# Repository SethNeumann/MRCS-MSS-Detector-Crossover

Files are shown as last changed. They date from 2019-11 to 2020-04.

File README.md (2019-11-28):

# Modular Signaling System Crossover board cpOD-M
## License: CERN Open Hardware Licence v1.2

This Barry Draper design conforms to the 
[Modular Signaling System](http://modularsignalsystem.info/index.html)
(MSS) standard, first described by Greg Fuhriman in RMJ in the
1990s, as well as the proposed MSS 2.0 standard.  MSS is widely
used in the Free-mo world, but its also a great solution for a
layout needing basic ABS signaling.  A Crossover board is for a
non-signaled module (detection only).  The MSS Detector Crossover
Board includes a power supply that is fed by the Free-mo Aux Bus
(12 to 14 Volt AC or DCC) and has connectors to communicate with
two adjacent modules and a socket for current detector such as a
[cpOD-M](http://www.modelrailroadcontrolsystems.com/cpod-control-point-occupancy-detector/)
or Dr. Chubb's
[DCCOD](https://www.jlcenterprises.net/products/dcc-optimized-detector).
The MSS Crossover, a cpOD-M, and two straight-through network cables
are all you need to add signal detection to a single track Free-mo
module. (As expected, two of each would be needed for a double track
module.)

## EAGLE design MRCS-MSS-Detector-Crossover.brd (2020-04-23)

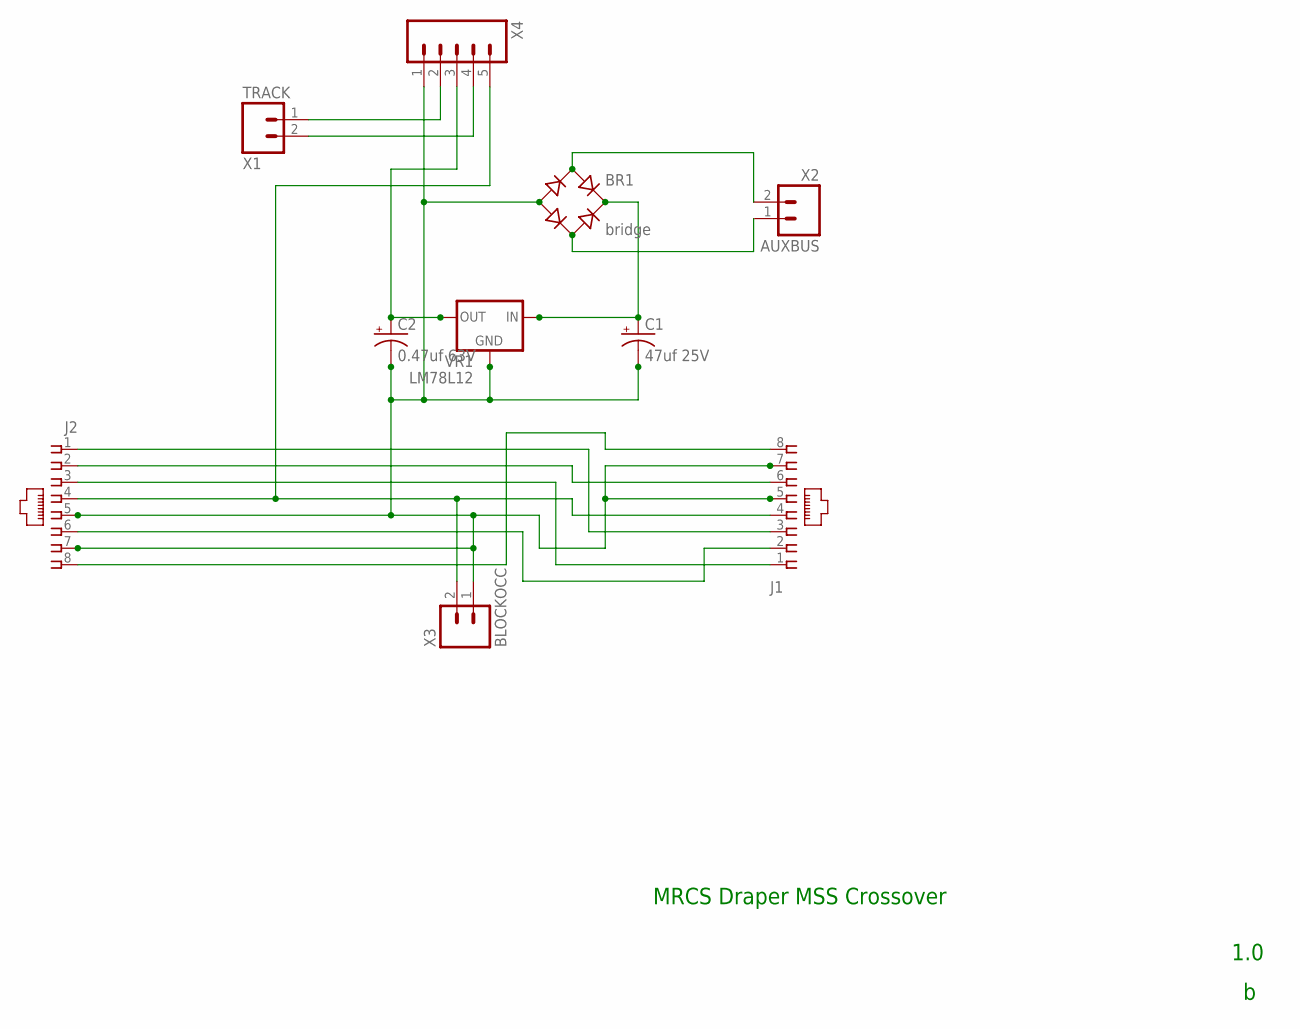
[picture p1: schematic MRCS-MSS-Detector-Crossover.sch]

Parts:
BR1: bridge; RB1A
C1: 47uf 25V; E2.5-6
C2: 0.47uf 63V; E2.5-6
J1, J2: CONNECTOR-RJ45-FRONT; RJ45-NO-SHIELD
VR1: LM78L12; TO-92
X1: TRACK; SCREWTERMINAL-5MM-2
X2: AUXBUS; SCREWTERMINAL-5MM-2
X3: BLOCKOCC; SCREWTERMINAL-5MM-2
X4: CONNECTOR-M051.56; KK-156-5

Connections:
AC1: BR1.AC1, X2.2 (B)
AC2: BR1.AC2, X2.1 (A)
GND: BR1.-, C1.-, C2.-, J1.5, J1.7, J2.5, J2.7, VR1.1 (GND), X3.1 (A), X4.1
unnamed: J1.3, J2.1
unnamed: J1.6, J2.2
unnamed: J1.1, J2.3
unnamed: J1.4, J2.4, X3.2 (B), X4.5
unnamed: J1.2, J2.6
unnamed: J1.8, J2.8
TRACK1: X1.1 (A), X4.2
TRACK2: X1.2 (B), X4.4
V12: C2.+, VR1.3 (OUT), X4.3
VIN: BR1.+, C1.+, VR1.2 (IN)

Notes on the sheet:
MRCS Draper MSS Crossover
1.0

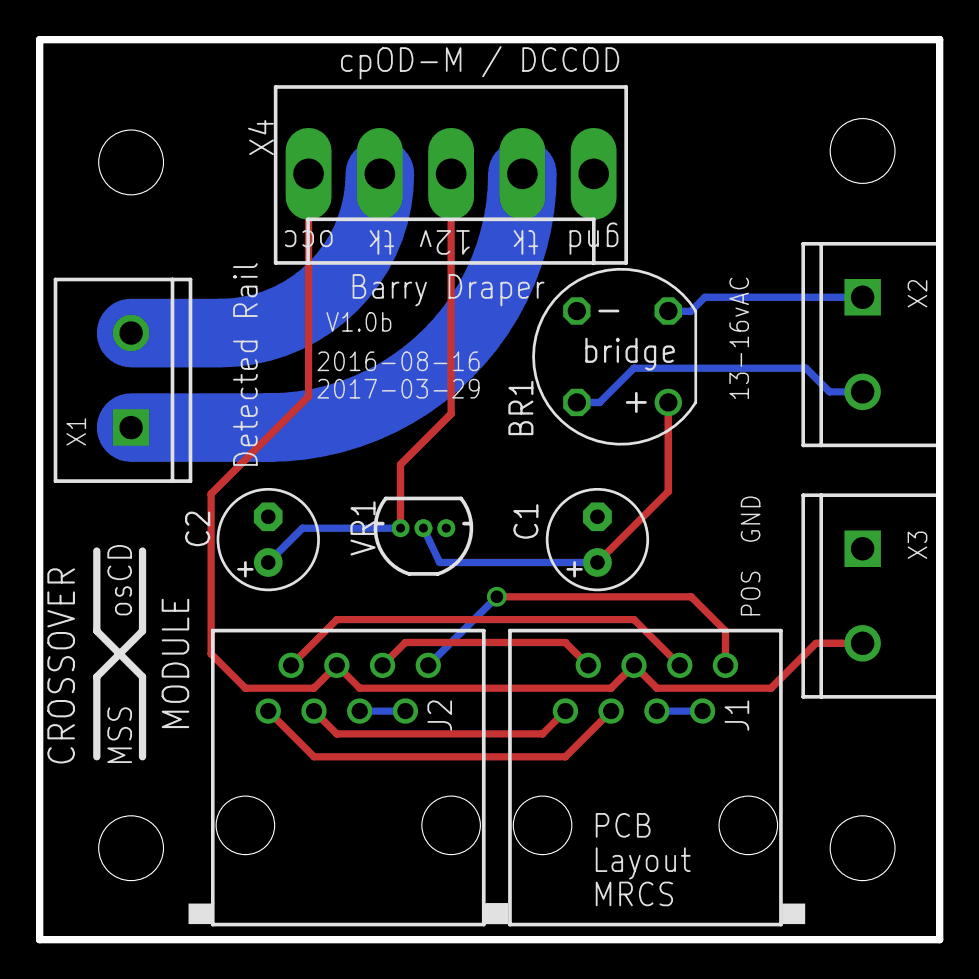
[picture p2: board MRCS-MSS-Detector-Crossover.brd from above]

Board: 2 copper layers, 50.0 x 50.0 mm, 10 parts (0 on the bottom side), 13 nets.

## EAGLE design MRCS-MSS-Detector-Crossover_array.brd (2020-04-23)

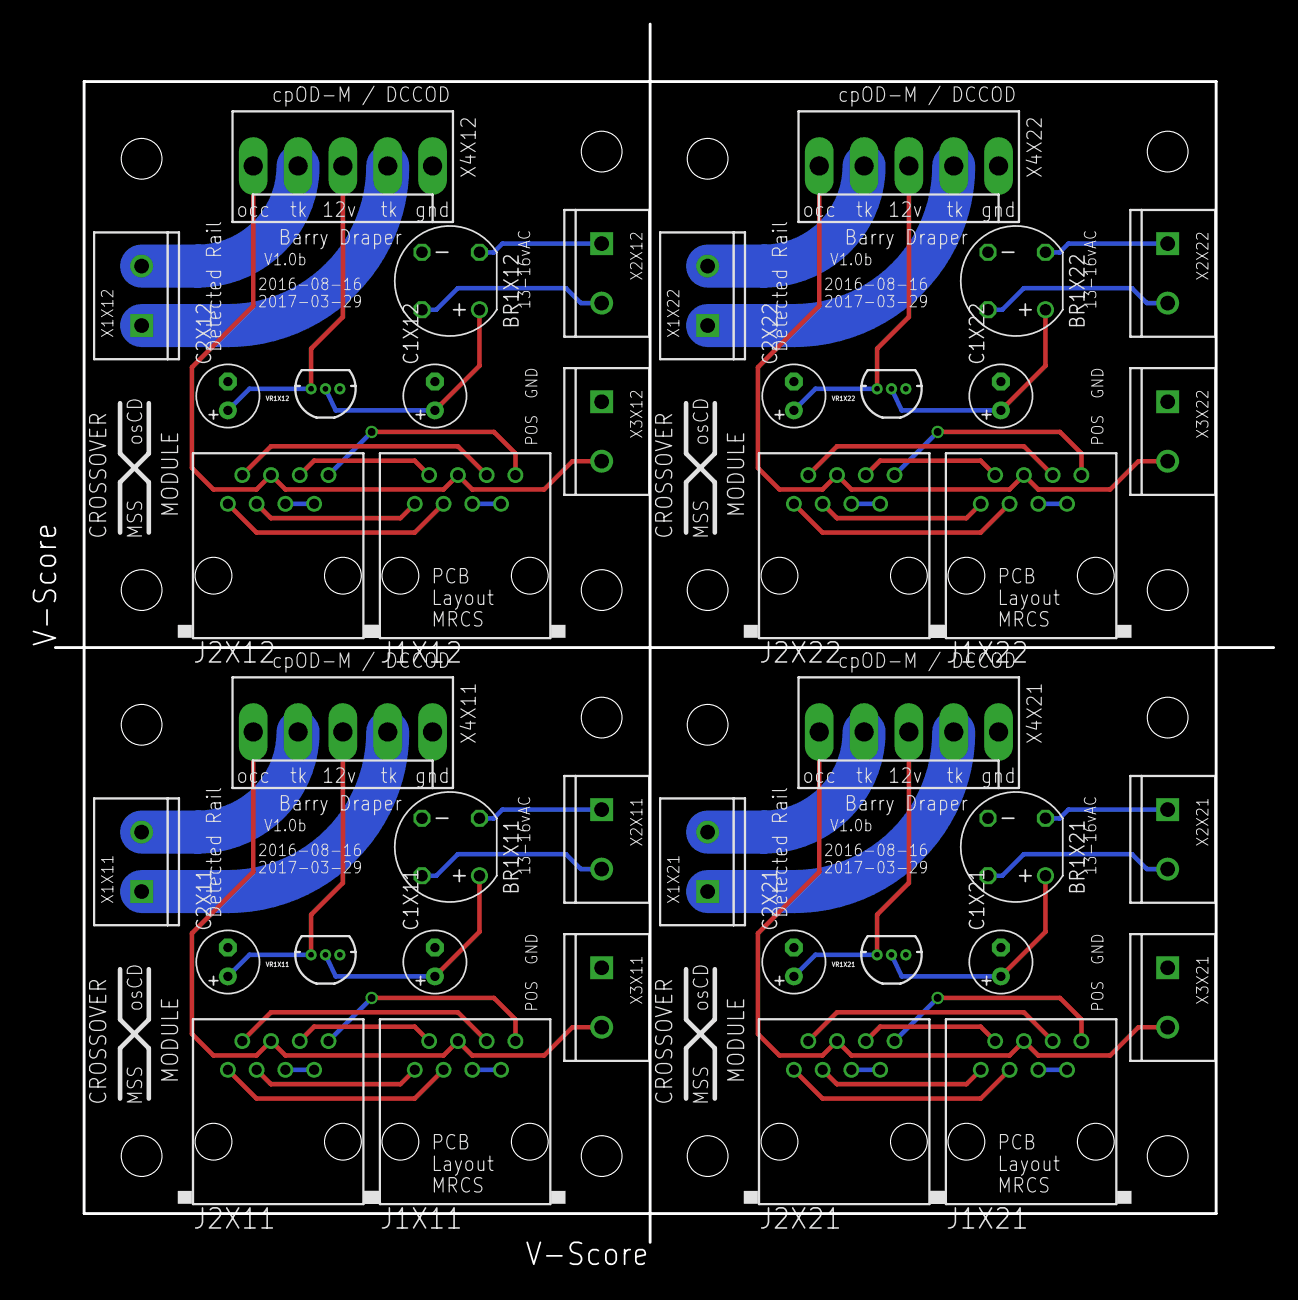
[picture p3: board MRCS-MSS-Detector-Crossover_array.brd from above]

Board: 2 copper layers, 107.6 x 107.6 mm, 40 parts (0 on the bottom side), 52 nets.

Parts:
BR1X11, BR1X12, BR1X21, BR1X22: RB1A
C1X11, C1X12, C1X21, C1X22, C2X11, C2X12, C2X21, C2X22: E2.5-6
J1X11, J1X12, J1X21, J1X22, J2X11, J2X12, J2X21, J2X22: RJ45-NO-SHIELD
VR1X11, VR1X12, VR1X21, VR1X22: TO-92
X1X11, X1X12, X1X21, X1X22, X2X11, X2X12, X2X21, X2X22, X3X11, X3X12, X3X21, X3X22: SCREWTERMINAL-5MM-2
X4X11, X4X12, X4X21, X4X22: KK-156-5

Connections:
AC1X11: BR1X11.AC1, X2X11.2
AC1X12: BR1X12.AC1, X2X12.2
AC1X21: BR1X21.AC1, X2X21.2
AC1X22: BR1X22.AC1, X2X22.2
AC2X11: BR1X11.AC2, X2X11.1
AC2X12: BR1X12.AC2, X2X12.1
AC2X21: BR1X21.AC2, X2X21.1
AC2X22: BR1X22.AC2, X2X22.1
GNDX11: BR1X11.-, C1X11.-, C2X11.-, J1X11.5, J1X11.7, J2X11.5, J2X11.7, VR1X11.1, X3X11.1, X4X11.1
GNDX12: BR1X12.-, C1X12.-, C2X12.-, J1X12.5, J1X12.7, J2X12.5, J2X12.7, VR1X12.1, X3X12.1, X4X12.1
GNDX21: BR1X21.-, C1X21.-, C2X21.-, J1X21.5, J1X21.7, J2X21.5, J2X21.7, VR1X21.1, X3X21.1, X4X21.1
GNDX22: BR1X22.-, C1X22.-, C2X22.-, J1X22.5, J1X22.7, J2X22.5, J2X22.7, VR1X22.1, X3X22.1, X4X22.1
unnamed: J1X11.3, J2X11.1
unnamed: J1X12.3, J2X12.1
unnamed: J1X21.3, J2X21.1
unnamed: J1X22.3, J2X22.1
unnamed: J1X11.6, J2X11.2
unnamed: J1X12.6, J2X12.2
unnamed: J1X21.6, J2X21.2
unnamed: J1X22.6, J2X22.2
unnamed: J1X11.1, J2X11.3
unnamed: J1X12.1, J2X12.3
unnamed: J1X21.1, J2X21.3
unnamed: J1X22.1, J2X22.3
unnamed: J1X11.4, J2X11.4, X3X11.2, X4X11.5
unnamed: J1X12.4, J2X12.4, X3X12.2, X4X12.5
unnamed: J1X21.4, J2X21.4, X3X21.2, X4X21.5
unnamed: J1X22.4, J2X22.4, X3X22.2, X4X22.5
unnamed: J1X11.2, J2X11.6
unnamed: J1X12.2, J2X12.6
unnamed: J1X21.2, J2X21.6
unnamed: J1X22.2, J2X22.6
unnamed: J1X11.8, J2X11.8
unnamed: J1X12.8, J2X12.8
unnamed: J1X21.8, J2X21.8
unnamed: J1X22.8, J2X22.8
TRACK1X11: X1X11.1, X4X11.2
TRACK1X12: X1X12.1, X4X12.2
TRACK1X21: X1X21.1, X4X21.2
TRACK1X22: X1X22.1, X4X22.2
TRACK2X11: X1X11.2, X4X11.4
TRACK2X12: X1X12.2, X4X12.4
TRACK2X21: X1X21.2, X4X21.4
TRACK2X22: X1X22.2, X4X22.4
V12X11: C2X11.+, VR1X11.3, X4X11.3
V12X12: C2X12.+, VR1X12.3, X4X12.3
V12X21: C2X21.+, VR1X21.3, X4X21.3
V12X22: C2X22.+, VR1X22.3, X4X22.3
VINX11: BR1X11.+, C1X11.+, VR1X11.2
VINX12: BR1X12.+, C1X12.+, VR1X12.2
VINX21: BR1X21.+, C1X21.+, VR1X21.2
VINX22: BR1X22.+, C1X22.+, VR1X22.2

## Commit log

2019-11-28 fix commas in xml
    [MRCS-MSS-Detector-Crossover.brd, MRCS-MSS-Detector-Crossover.sch]
2020-04-23 Moved all components into SPCoast.lbr and panelized
    [MRCS-MSS-Detector-Crossover.brd, MRCS-MSS-Detector-Crossover.sch, MRCS-MSS-Detector-Crossover_array.brd]
